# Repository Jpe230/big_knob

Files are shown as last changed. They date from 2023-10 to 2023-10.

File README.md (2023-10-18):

# Big Knob

A 3D printed single encoder volume knob.

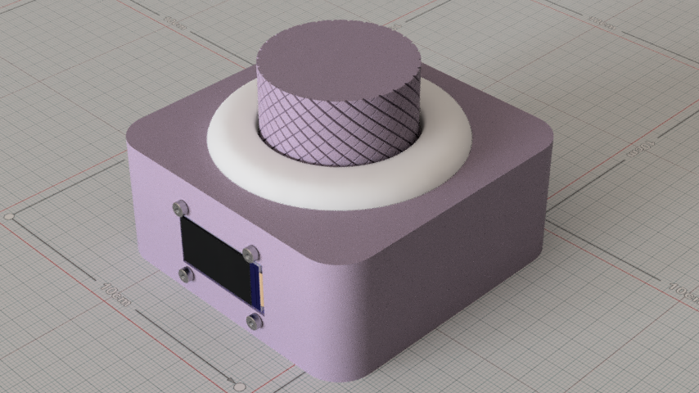
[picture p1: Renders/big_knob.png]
big_knob_render


Features:

- Simple to 3D print
- RGB lightning
- LCD support
- RP2040

It based on the works of [18Markus1984](https://github.com/18Markus1984/Volume-Knob/tree/main).

Photos:

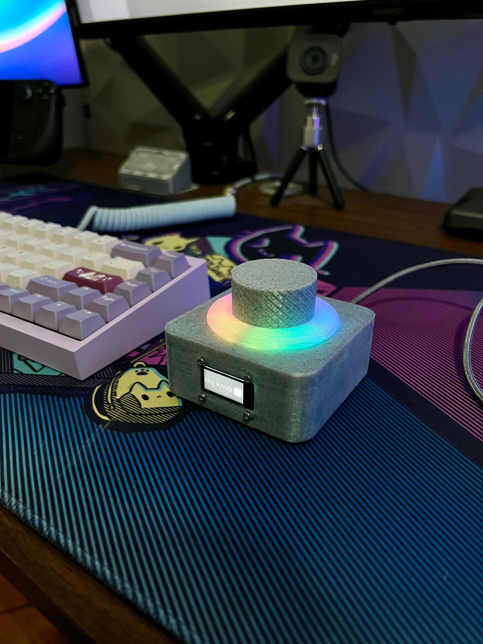
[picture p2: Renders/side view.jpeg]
big_knob_photo1


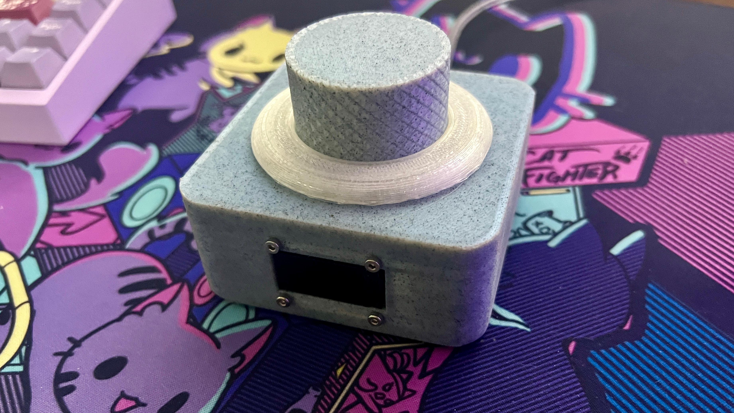
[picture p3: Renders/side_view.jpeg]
big_knob_photo2


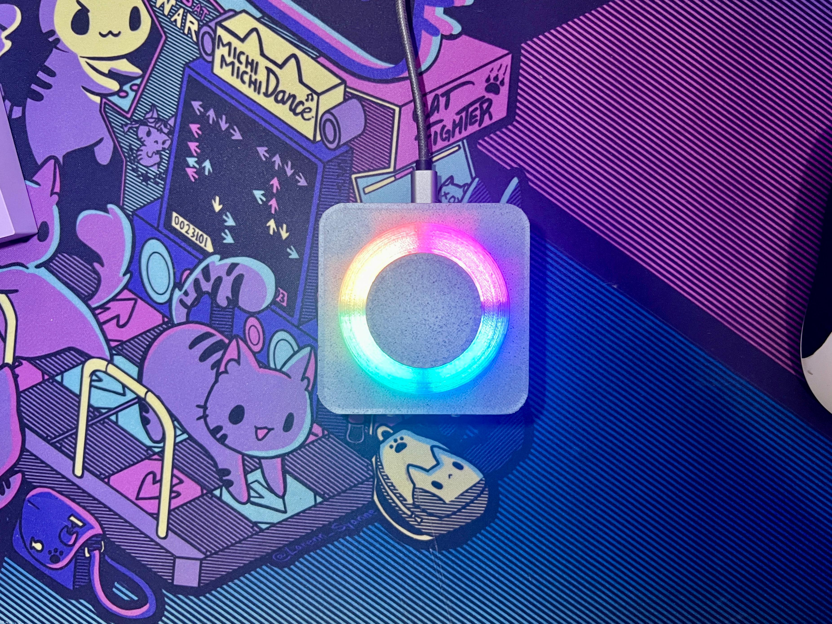
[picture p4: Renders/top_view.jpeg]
big_knob_photo3


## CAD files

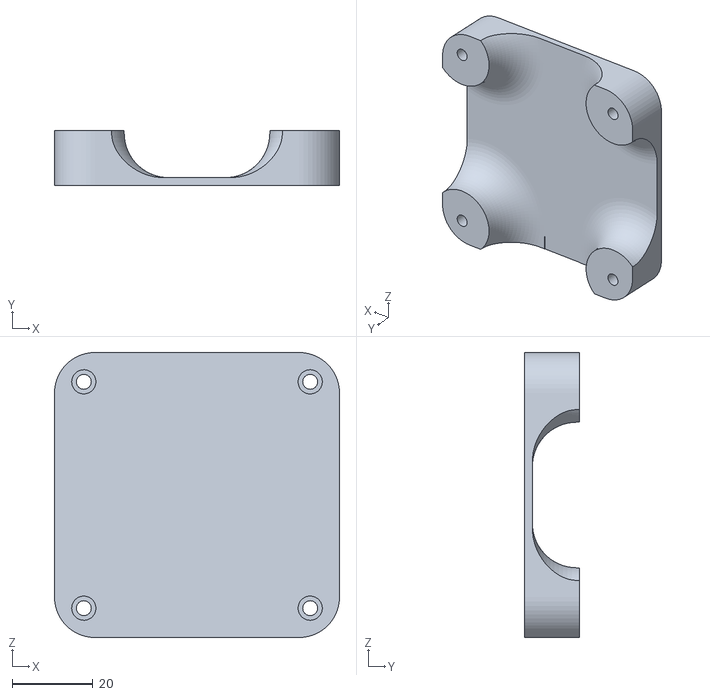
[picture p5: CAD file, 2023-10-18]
Case/stl/bottom_plate.stl
70.5 x 13.7 x 70.5

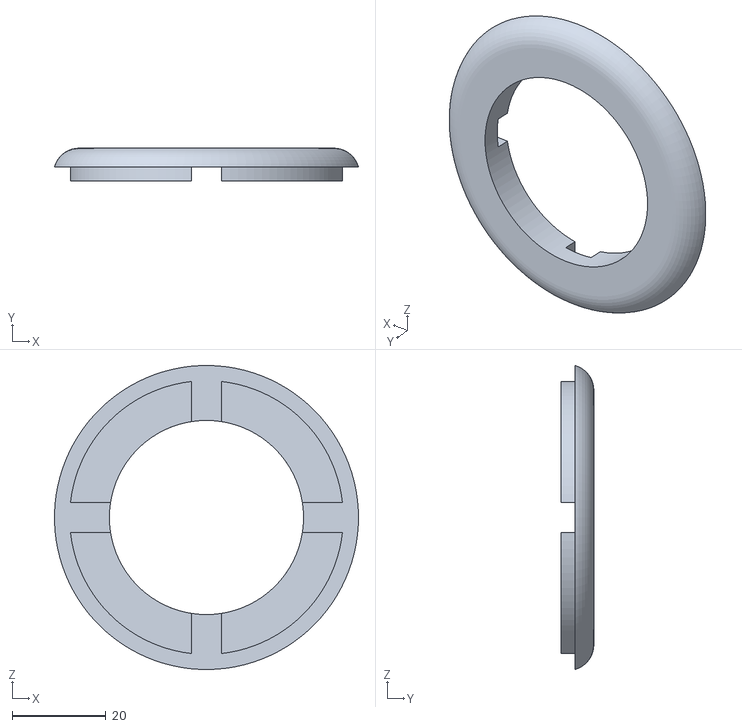
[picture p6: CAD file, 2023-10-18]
Case/stl/diffuser.stl
65.0 x 7.00 x 65.0

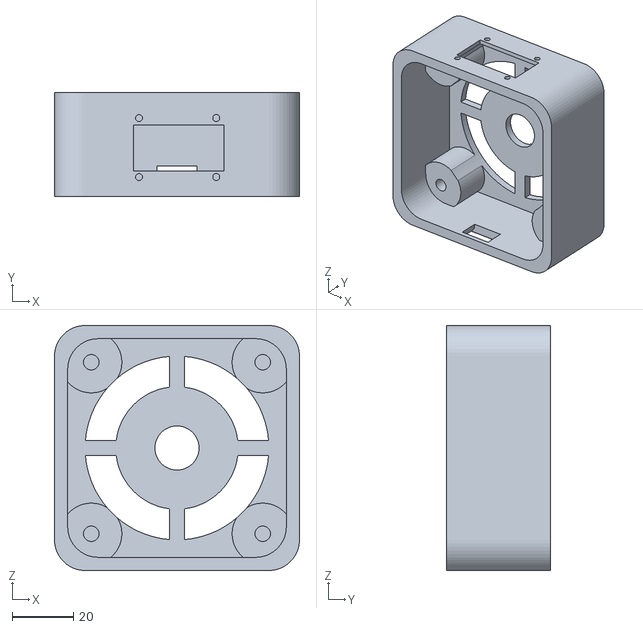
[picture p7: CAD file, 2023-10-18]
Case/stl/top_case.stl
80.0 x 34.0 x 80.0

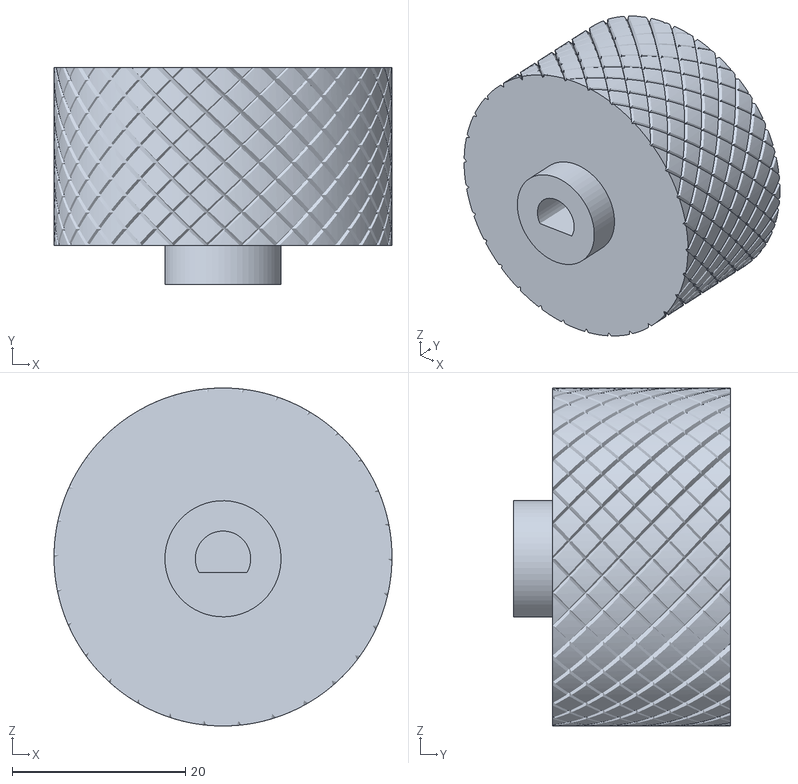
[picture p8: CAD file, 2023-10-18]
Case/stl/knob.stl
39.0 x 25.0 x 39.0

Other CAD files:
Case/Big_Knob_Case.f3d

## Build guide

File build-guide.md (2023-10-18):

# Build Guide

The Big Knob a 3d printed knob!

## Parts

### Required

| Name | Count | Remarks |
| :- | :- | :- |
| PCB  | 1 | [Gerber here](https://github.com/Jpe230/big_knob/blob/main/PCB/GERBER_PCB_Big_Knob.zip) |
| RP2040 Pro Micro | 1 | See notes
| EC11 Encoder | 1 | |
| WS2812B | 10 | |
| ST7735 80x160 (0.06inch)| 1 | [Screen used](https://aliexpress.com/item/1005005334510897.html) |
| Top case | 1 | [Link here](https://github.com/Jpe230/big_knob/blob/main/Case/stl/top_case.stl)|
| bottom plate | 1 | [Link here](https://github.com/Jpe230/big_knob/blob/main/Case/stl/bottom_plate.stl)|
| Diffuser | 1 | [Link here](https://github.com/Jpe230/big_knob/blob/main/Case/stl/diffuser.stl)|
| Knob | 1 | [Link here](https://github.com/Jpe230/big_knob/blob/main/Case/stl/knob.stl)|
| 8mm M3 screw | 4 ||
| 10mm M3 thread insert | 4 ||
| 4mm M2 screw | 4 ||
| M2 nut | 4 ||

#### Notes

Any RP2040 with a pro micro footprint should work, but the firmware must be modified, I used a Sparkfun PM2040

## Building

### Soldering the LEDS

The leds should be soldered with the arrow facing the bottom-right corner
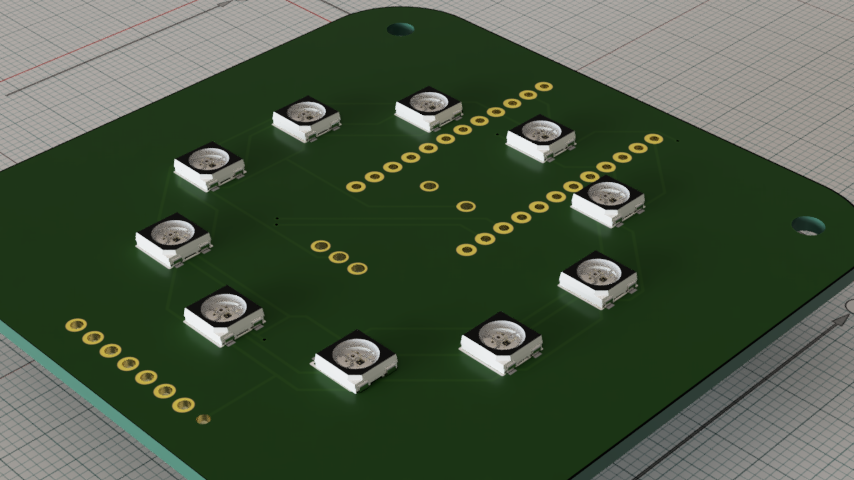
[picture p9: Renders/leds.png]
leds


### Soldering the Encoder

Remove the grounding tabs at the side of the cncoder and solder it\
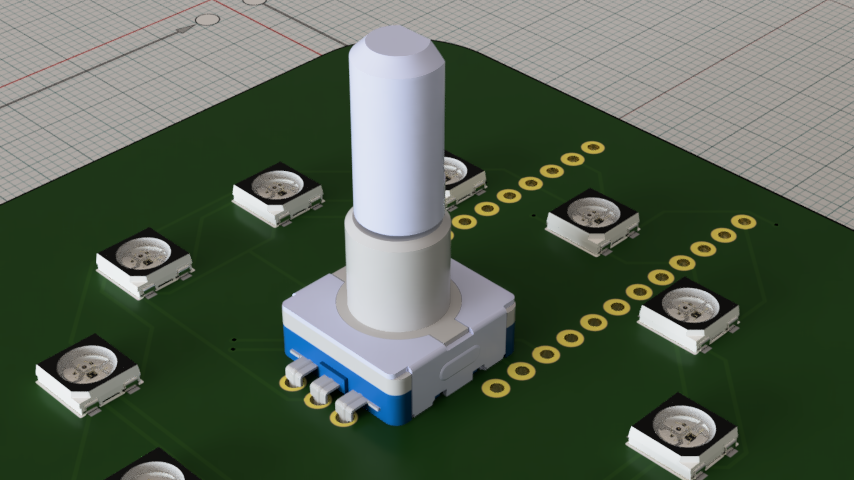
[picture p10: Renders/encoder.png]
ec11


### Soldering the RP2040

The RP2040 should be mounted facing down.
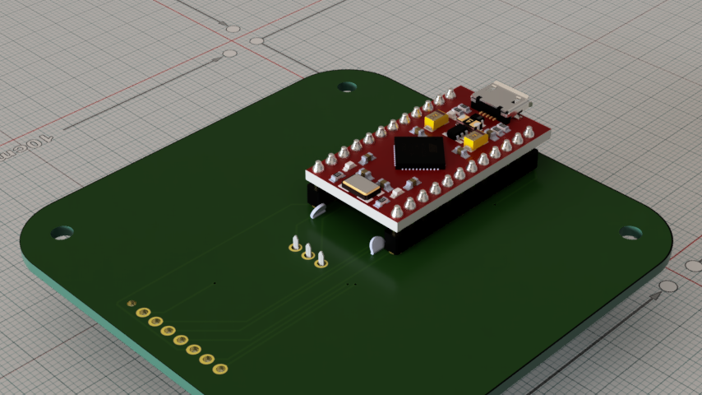
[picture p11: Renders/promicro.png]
rp2040


### Soldering the Screen

With some thin wire solder the adjacent pads with the corresponding pad on the PCB.
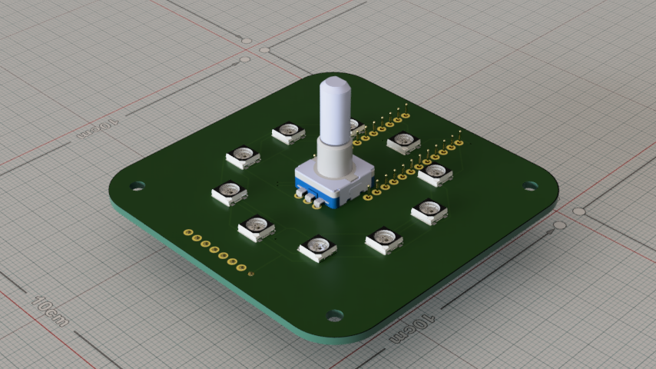
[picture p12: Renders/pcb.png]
pcb


## Mounting

1) Insert the screen into the slot of the top case
2) Insert the top 2 screws from the front and secure the screws with nuts
3) Insert the PCB into the top case
4) Insert the remaining screws to the designated holes and secure them with nuts.
5) Attach the bottom plate and secure it the M3 screws.

## Flashing

To compile the firmware please use QMK:

```
qmk compile -kb jpe230/big_knob -km default
```
